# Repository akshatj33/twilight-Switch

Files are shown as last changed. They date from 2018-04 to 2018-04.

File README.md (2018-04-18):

# twilight-Switch
This is the embedded C code and the schematic and board layout for my project on twilight switch.

The timely operation of street lights, porch lights and other forms of outdoor illumination is required for the twin
concerns of safety and environment protection; lights operated too late are a safety hazard, while lights operated
too early are a waste of power. The switching on and off of external lightings can be set with the help of the device
called Twilight Switch.
Traditionally switching has been controlled via a human operator or the automatic control is accomplished
using a light sensor like LDR, photosensitive cells etc. However the use of sensors is accompanied by
wastage of power deterioration over time due to incessant exposure to atmosphere and environmental
changes leading to regular maintenance.
A Twilight switch provides a mechanism by which a light bulb can be turned ON and OFF automatically
without human interference. This project is a time based solution. This mechanism works on civil twilight
time. Component used for human interface is LCD where data such as date, month, year, city and the
present time (hh:mm:ss) are entered. From the algorithm, twilight time i.e. civil-dusk and civil-dawn time of
that place is calculated.
RTC (PCF8563) is used to maintain time. As an when the civil dusk time matches with RTC, the light (here
bulb) is switched ON and remains in this state till civil-dawn time where it is toggled.
We have fabricated 2 boards. First (4*3) is the DC Circuit board which has our microcontroller
(MSP430G2553) and LCD (HD44780U). Second (3*1) is the AC circuit board which has a triac (BT136)
whose 2 of the 3 gate requires AC. We are using triac instead of a relay because SSD switches are better
than mechanical ones. To isolate the AC portion of the circuit from the DC one we have used an optoisolator
(MOC 3041).

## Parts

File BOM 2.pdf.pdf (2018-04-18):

Reference | Value | Note
74HC595 | DIP16 | 8-Bit Shift Register
BUZ | | Male Header
C2 | 0.1uF | Ceramic
C4 | 0.1uF | Ceramic
D1 | 1N5819 | Diode
DISP1 | | 16X2 LCD
LCD | | Male Header
MPX1 | | Male Header
PWR | | Male Header
R1 | 1k
R3 | 10k
R5 | 1k
R7 | 1k
R9 | 1k
RN1 | 1k | Resistor Network
S1 | OMRON SWITCH | 10XX
S3 | OMRON SWITCH | 10XX
S5 | OMRON SWITCH | 10XX
S7 | OMRON SWITCH | 10XX
S9 | OMRON SWITCH | 10XX
S11 | OMRON SWITCH | 10XX
S13 | OMRON SWITCH | 10XX
ALARM | | Male Header
C1 | 0.1uF | Ceramic
C3 | 22pF | Ceramic
CR2032 | 3V | Battery with holder
D2 | 1N5819 | Diode
I2C | | Male Header
LED1 | LED3MM | Red
MPX2 | | Male Header
Q1 | 32678Hz | Crystal
R2 | 10k
R4 | 470
R6 | 1k
R8 | 1k
REG | | Male Header
RTC | PCF8563DIP | RTC, 8-Pin
S2 | OMRON SWITCH | 10XX
S4 | OMRON SWITCH | 10XX
S6 | OMRON SWITCH | 10XX
S8 | OMRON SWITCH | 10XX
S10 | OMRON SWITCH | 10XX
S12 | OMRON SWITCH | 10XX
1

S14 | OMRON SWITCH | 10XX
S15 | OMRON SWITCH | 10XX
S16 | OMRON SWITCH | 10XX
SR1 | LED3MM | Red
SR3 | LED3MM | Red
SR5 | LED3MM | Red
SR7 | LED3MM | Red
SUP | | Male Header
SW1 | OMRON SWITCH | 10XX
VR3 | 10k | PRESET
SG1 | 5V | BUZZER
SR2 | LED3MM | Red
SR4 | LED3MM | Red
SR6 | LED3MM | Red
SR8 | LED3MM | Red
SW | SLIDESWITCH BIG
SWC | | Male Header

All resistors are 1/8W, 5% CFR.

2

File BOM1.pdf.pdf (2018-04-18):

Reference | Value | Note | Estimated Cost
ANALOG | M05 | Male Header
CHARLIE | M03 | Male Header
DISP1 | 7-SEG_4D | Display
LDR | 1k | 3MM
LED2 | LED5MM | Red
LED4 | LED5MM | Red
LED6 | LED5MM | Red
POT | 10k | Potentiometer
R1 | 1k
R3 | 1k
R5 | 330
R7 | 220
R9 | 150
R11 | 1K
R13 | 10K
R15 | 10K
R17 | 10K
R19 | 1k
R21 | 1k
R23 | 1k
R25 | 1k
R27 | 10k
BLUE | LED5MM
DIGIT | M05 | Male Header
GREEN | LED5MM | LED5MM
LED1 | LED5MM | Red
LED3 | LED5MM | Red
LED5 | LED5MM | Red
NTC | M02 | 1k
PWR | M05 | Male Header
R2 | 1k
R4 | 10K
R6 | 10K
R8 | 10K
R10 | 1K
R12 | 1K
R14 | 10K
R16 | 10K
R18 | 1k
R20 | 1k
R22 | 1k
R24 | 1k
R26 | 10k
R28 | 10k
1

R29 | 10k
RED | LED5MM | LED5MM
SEGMENT | M08 | Male Header
SW2 | 10-XX | OMRON SWITCH
SW4 | 10-XX | OMRON SWITCH
T1 | BC547 | NPN Transistor
T3 | BC547 | NPN Transistor
T5 | BC547 | NPN Transistor
T7 | BC547 | NPN Transistor
WIRE1 | | 22 Gauge
RGB | M04 | Male Header
SW1 | 10-XX | OMRON SWITCH
SW3 | 10-XX | OMRON SWITCH
SW5 | 10-XX | OMRON SWITCH
T2 | BC547 | NPN Transistor
T4 | BC547 | NPN Transistor
T6 | BC547 | NPN Transistor
TOUCH | M02 | Male Header
WIRE2 | | 22 Gauge

2

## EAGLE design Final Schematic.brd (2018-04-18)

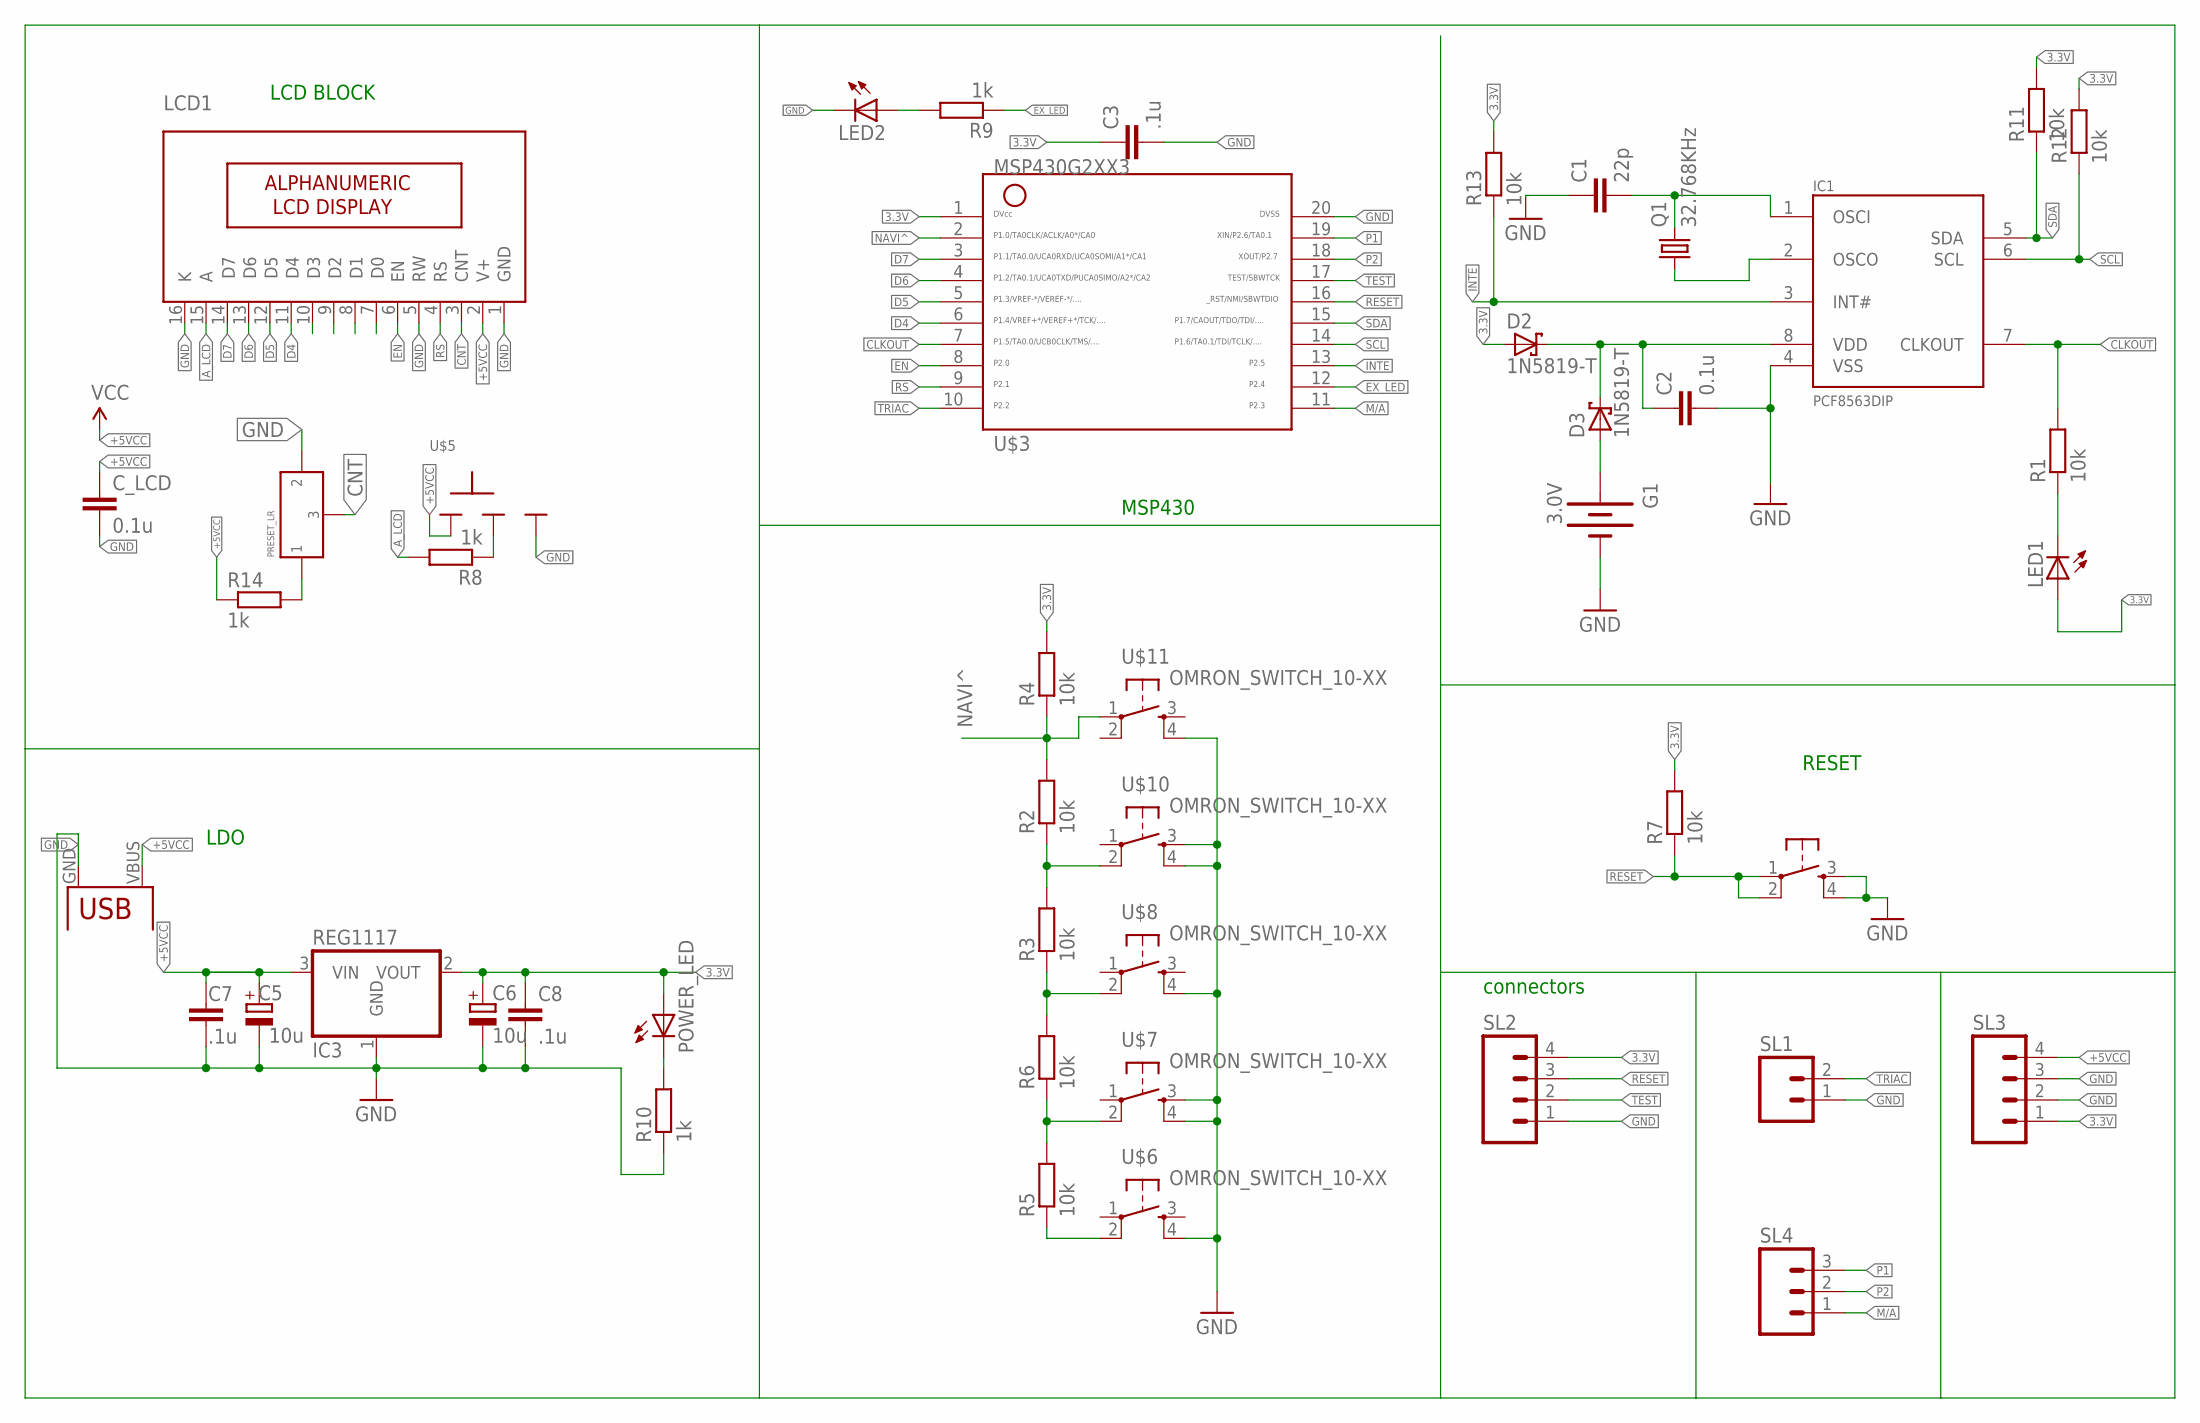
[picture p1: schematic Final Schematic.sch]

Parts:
C1: 22p; C025-025X050
C2: 0.1u; C025-025X050
C3, C7, C8: .1u; C025-025X050
C5, C6: 10u; E2,5-5
C_LCD: 0.1u; C025-025X050
D2, D3: 1N5819-T; DO41-7.6
G1: 3.0V; BATTCOM_20MM_PTH
IC1: PCF8563DIP; DIL08
IC3: REG1117; SOT223
LCD1: 16X2LCD; 16X2_LCD
LED1, LED2: LED3MM
POWER_LED: LED3MM
Q1: 32.768KHz; TC26H
R1, R2, R3, R4, R5, R6, R7, R11, R13: 10k; 0207/7
R8, R10, R14: 1k; 0207/7
R9: 1k; 0207/10
R12: 10k; 0207/10
SL1: M02; 02P
SL2, SL3: M04; 04P
SL4: M03; 03P
U$1: PRESET_LR
U$2: USB(POWER)
U$3: MSP430G2553DIP20; G2553-DIP20
U$5: SLIDESWITCH-BIG; BIGSWITCH
U$6, U$7, U$8, U$9, U$10, U$11: OMRON_SWITCH_10-XX; B3F-10XX

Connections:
3.3V: C3.1, C6.+, C8.1, D2.A, IC3.2 (VOUT), LED1.A, POWER_LED.A, R4.2, R7.2, R11.2, R12.2, R13.2, SL2.4, SL3.1, U$3.1
+5VCC: C5.+, C7.1, C_LCD.1, IC3.3 (VIN), LCD1.2 (V+), R14.1, SL3.4, U$2.VBUS (VCC), U$5.1
A_LCD: LCD1.15 (A), R8.2
CLKOUT: IC1.7 (CLKOUT), R1.2, U$3.7
CNT: LCD1.3 (CNT), U$1.P$3 (3)
D4: LCD1.11 (D4), U$3.6
D5: LCD1.12 (D5), U$3.5
D6: LCD1.13 (D6), U$3.4
D7: LCD1.14 (D7), U$3.3
EN: LCD1.6 (EN), U$3.8
EX_LED: R9.1, U$3.12
GND: C1.1, C2.2, C3.2, C5.-, C6.-, C7.2, C8.2, C_LCD.2, G1.2 (-), IC1.4 (VSS), IC3.1 (GND), LCD1.1 (GND), LCD1.5 (RW), LCD1.16 (K), LED2.K (C), R10.1, SL1.1, SL2.1, SL3.2, SL3.3, U$1.P$2 (2), U$2.GND, U$3.20, U$5.3, U$6.4 (S1), U$7.3 (S), U$7.4 (S1), U$8.4 (S1), U$9.3 (S), U$9.4 (S1), U$10.3 (S), U$10.4 (S1), U$11.4 (S1)
INTE: IC1.3 (INT#), R13.1, U$3.13
M/A: SL4.1, U$3.11
unnamed: R8.1, U$5.2
unnamed: LED2.A, R9.2
unnamed: LED1.K (C), R1.1
unnamed: R14.2, U$1.P$1 (1)
unnamed: R5.1, U$6.2 (P1)
unnamed: R2.1, R3.2, U$10.2 (P1)
unnamed: POWER_LED.K (C), R10.2
unnamed: R3.1, R6.2, U$8.2 (P1)
unnamed: C2.1, D2.C, D3.C, IC1.8 (VDD)
unnamed: C1.2, IC1.1 (OSCI), Q1.2
unnamed: IC1.2 (OSCO), Q1.1
unnamed: D3.A, G1.1 (+)
unnamed: R5.2, R6.1, U$7.2 (P1)
NAVI^: R2.2, R4.1, U$3.2, U$11.1
P1: SL4.3, U$3.19
P2: SL4.2, U$3.18
RESET: R7.1, SL2.3, U$3.16, U$9.1, U$9.2 (P1)
RS: LCD1.4 (RS), U$3.9
SCL: IC1.6 (SCL), R12.1, U$3.14
SDA: IC1.5 (SDA), R11.1, U$3.15
TEST: SL2.2, U$3.17
TRIAC: SL1.2, U$3.10

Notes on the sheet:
LCD BLOCK
RESET
connectors
LDO
MSP430

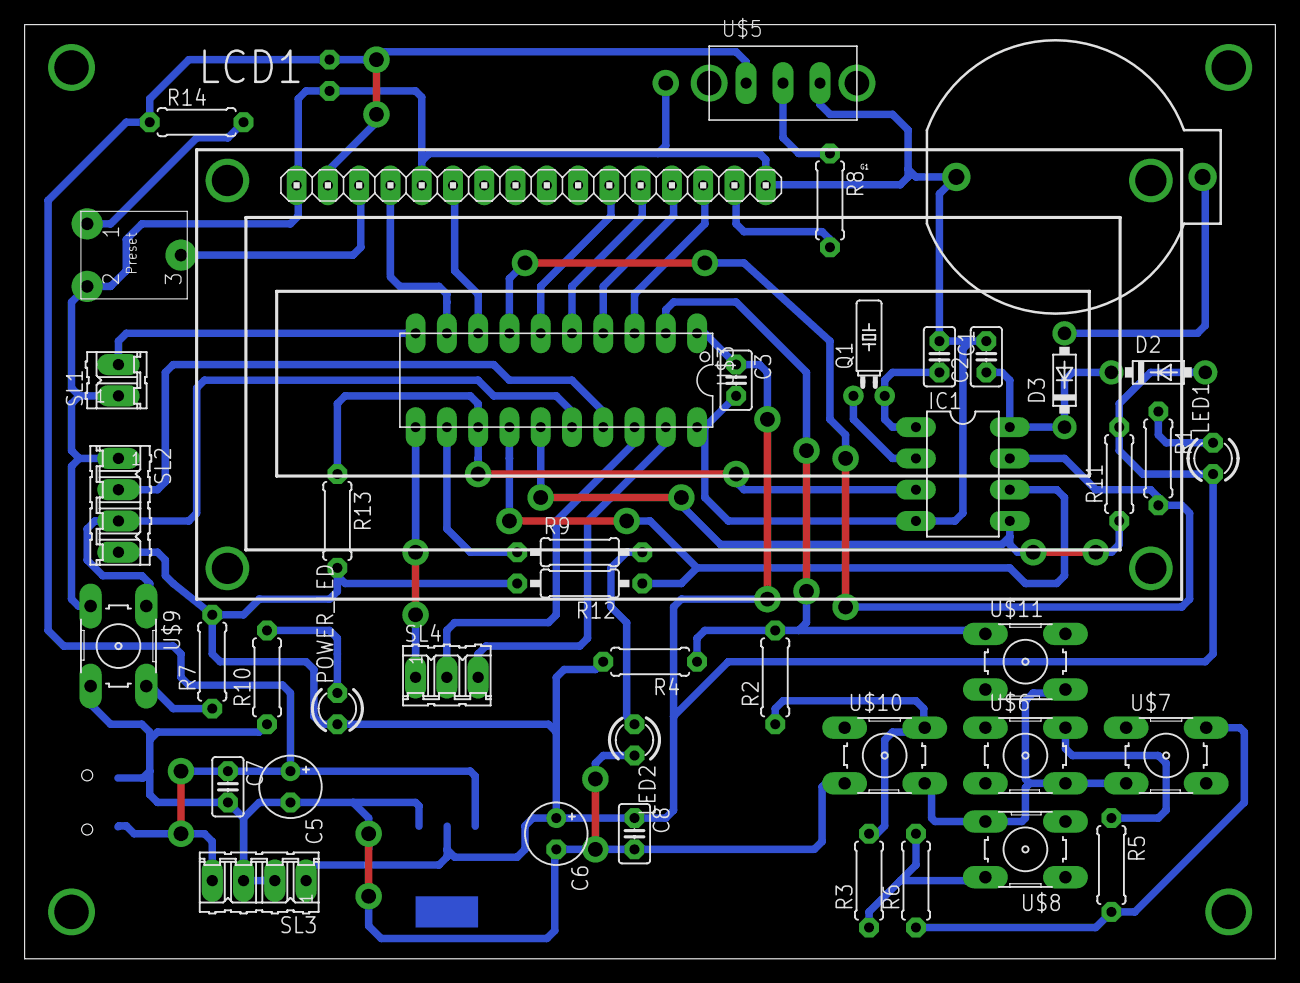
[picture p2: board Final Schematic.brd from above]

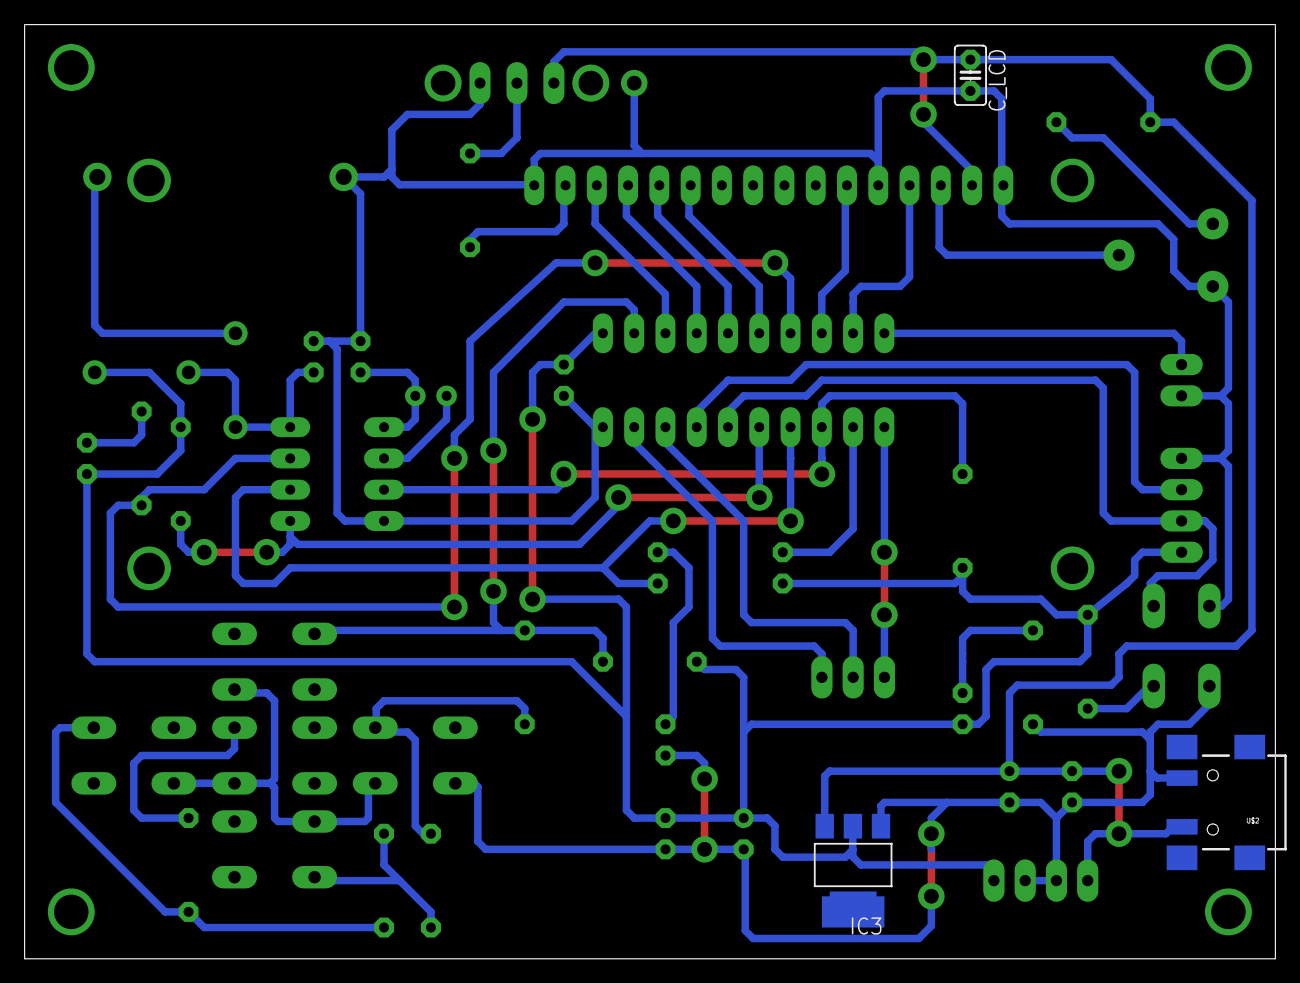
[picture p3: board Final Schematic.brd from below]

Board: 2 copper layers, 101.6 x 75.9 mm, 46 parts (3 on the bottom side), 36 nets.

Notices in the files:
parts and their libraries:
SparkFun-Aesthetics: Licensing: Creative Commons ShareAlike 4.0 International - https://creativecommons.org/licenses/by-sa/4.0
